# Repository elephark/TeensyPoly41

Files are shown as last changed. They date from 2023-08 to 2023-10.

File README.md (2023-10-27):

# TeensyPoly41

This is loosely based on [TeensyPoly6](https://github.com/albnys/TeensyPoly6)'s schematic, but with many changes of various significance:

* It uses a Teensy 4.1, as the 3.5 wasn't available when this was designed (and is now discontinued).
* It takes the form of a single 2-layer PCB with all pots, switches, and buttons directly affixed. I suppose you could run wires to a front panel if you *really* wanted to.
* It leans much more heavily into the multiplexers, with 8 instead of 1. This results in a more efficient use of pins. 
* It adds a few more controls and enables full ADSR envelopes on the amp and filter.
* It adds LEDs to indicate system state (and greatly aid debugging).
* It adds a rotary dial to select the desired MIDI channel.

### What it looks like
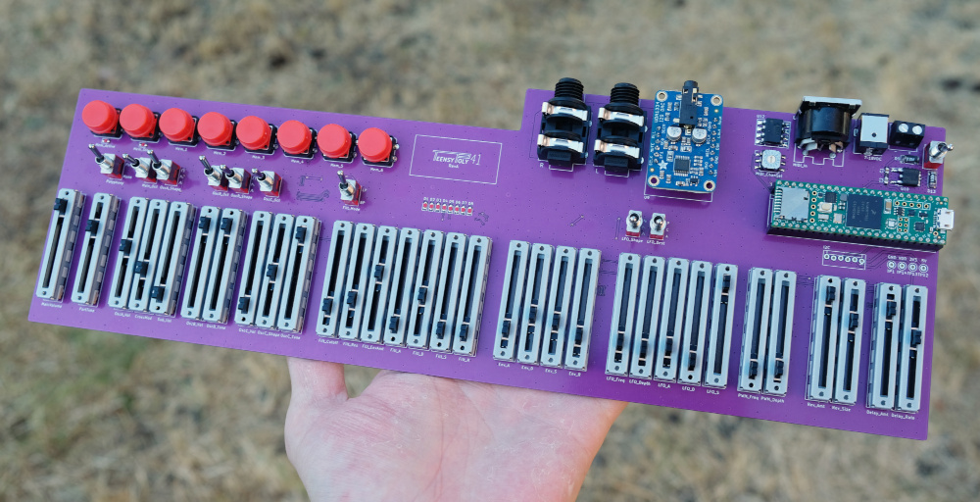
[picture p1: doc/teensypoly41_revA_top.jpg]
TeensyPoly41 top view

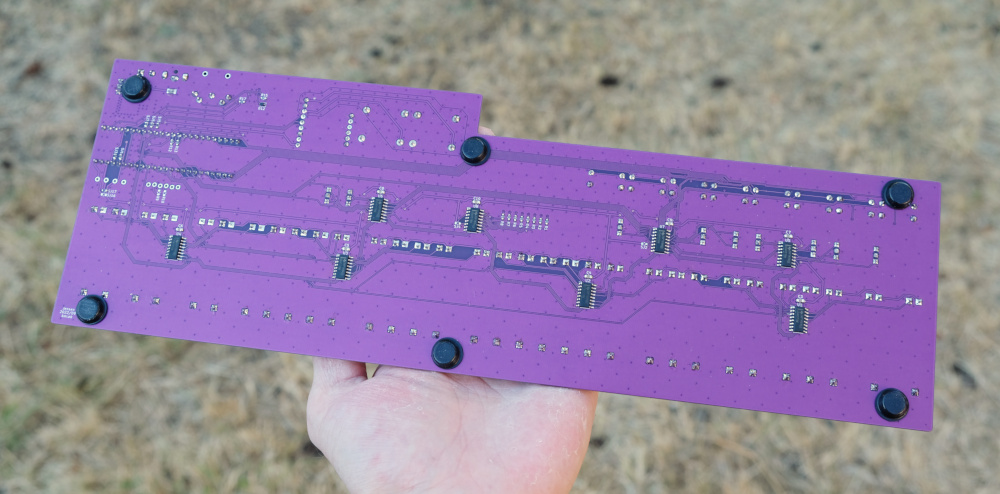
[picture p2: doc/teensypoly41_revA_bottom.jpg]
TeensyPoly41 bottom view


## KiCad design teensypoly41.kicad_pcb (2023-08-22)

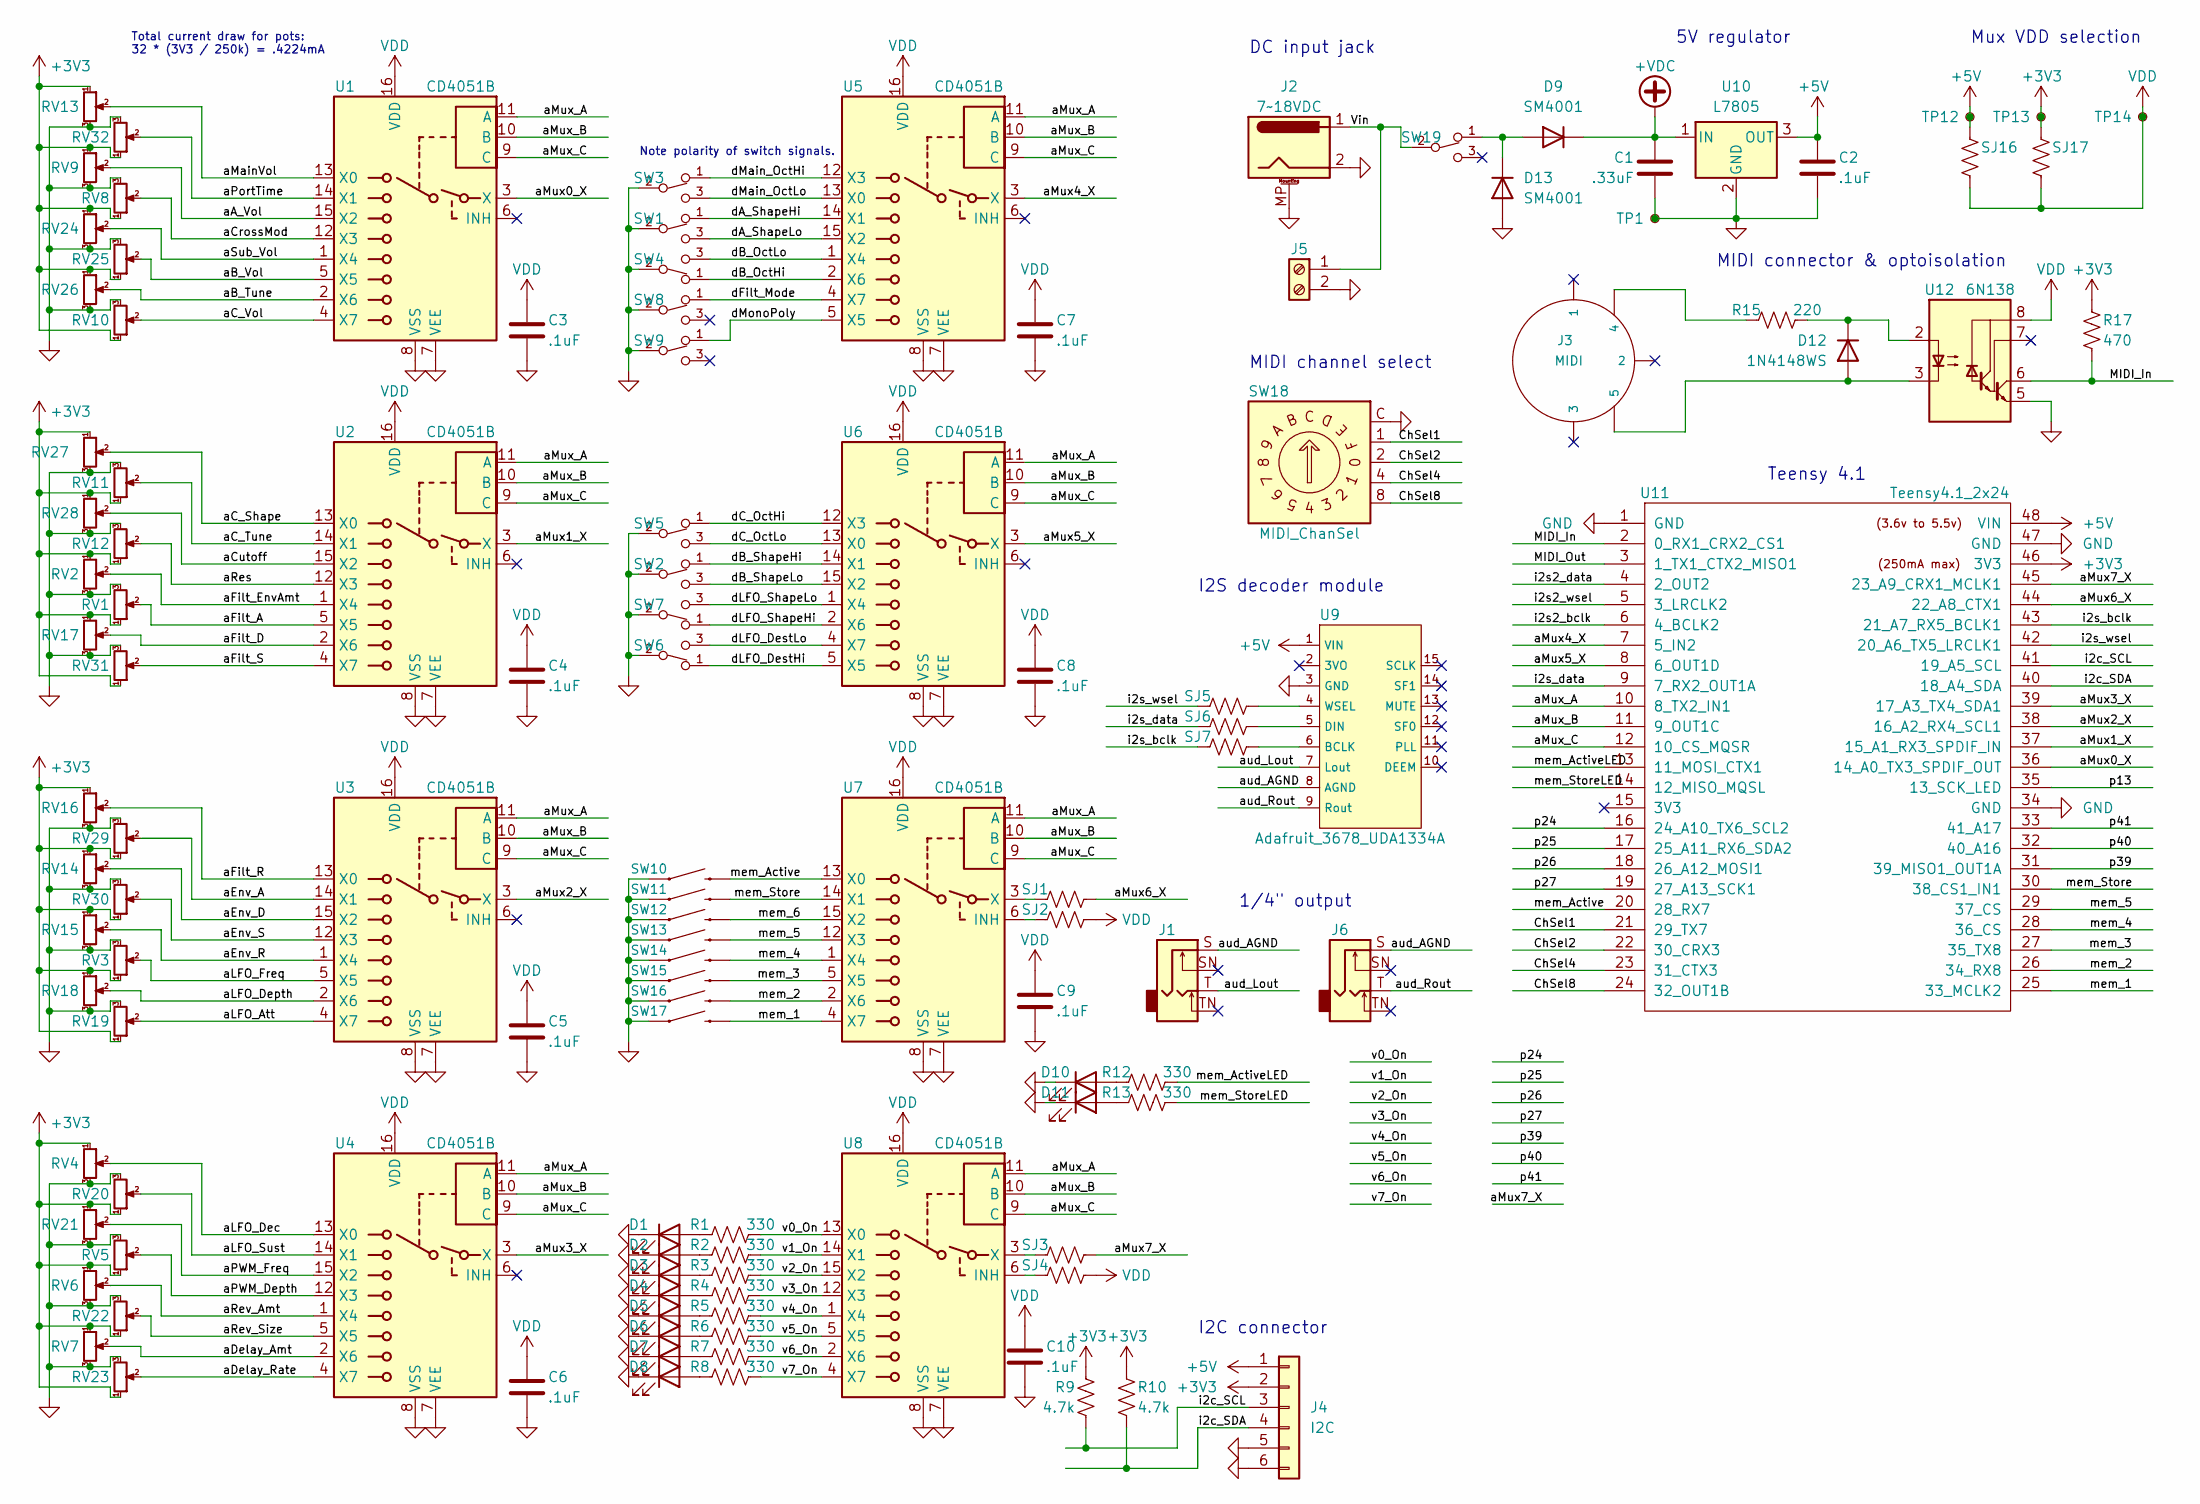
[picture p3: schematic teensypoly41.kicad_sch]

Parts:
C1: .33uF; C_0805_2012Metric_Pad1.18x1.45mm_HandSolder
C2, C3, C4, C5, C6, C7, C8, C9, C10: .1uF; C_0805_2012Metric_Pad1.18x1.45mm_HandSolder
D1: voice0; LED_0805_2012Metric_Pad1.15x1.40mm_HandSolder
D2: voice1; LED_0805_2012Metric_Pad1.15x1.40mm_HandSolder
D3: voice2; LED_0805_2012Metric_Pad1.15x1.40mm_HandSolder
D4: voice3; LED_0805_2012Metric_Pad1.15x1.40mm_HandSolder
D5: voice4; LED_0805_2012Metric_Pad1.15x1.40mm_HandSolder
D6: voice5; LED_0805_2012Metric_Pad1.15x1.40mm_HandSolder
D7: voice6; LED_0805_2012Metric_Pad1.15x1.40mm_HandSolder
D8: voice7; LED_0805_2012Metric_Pad1.15x1.40mm_HandSolder
D9, D13: SM4001; D_MELF
D10: MemActive; LED_0805_2012Metric_Pad1.15x1.40mm_HandSolder
D11: MemStore; LED_0805_2012Metric_Pad1.15x1.40mm_HandSolder
D12: 1N4148WS; D_SOD-323
J1: AudioJack_L; Jack_6.35mm_Neutrik_NMJ4HFD2_Horizontal
J2: 7~18VDC; BarrelJack_CUI_PJ-063AH_Horizontal
J3: MIDI; DIN5-RA-PTH
J4: I2C; MOLEX-1X6_LOCK
J5: Screw_Terminal_01x02; TerminalBlock_Phoenix_MKDS-1,5-2-5.08_1x02_P5.08mm_Horizont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
J6: AudioJack_R; Jack_6.35mm_Neutrik_NMJ4HFD2_Horizontal
R1, R2, R3, R4, R5, R6, R7, R8, R12, R13: 330; R_0603_1608Metric
R9, R10: 4.7k; R_0603_1608Metric
R15: 220; R_0603_1608Metric
R17: 470; R_0603_1608Metric
RV1: Filt_A; Alps_RS301111J00J
RV2: Filt_EnvAmt; Alps_RS301111J00J
RV3: LFO_Freq; Alps_RS301111J00J
RV4: LFO_D; Alps_RS301111J00J
RV5: PWM_Depth; Alps_RS301111J00J
RV6: Rev_Amt; Alps_RS301111J00J
RV7: Delay_Amt; Alps_RS301111J00J
RV8: CrossMod; Alps_RS301111J00J
RV9: OscA_Vol; Alps_RS301111J00J
RV10: OscC_Vol; Alps_RS301111J00J
RV11: OscC_Tune; Alps_RS301111J00J
RV12: Filt_Res; Alps_RS301111J00J
RV13: MainVolume; Alps_RS301111J00J
RV14: Env_D; Alps_RS301111J00J
RV15: Env_R; Alps_RS301111J00J
RV16: Filt_R; Alps_RS301111J00J
RV17: Filt_D; Alps_RS301111J00J
RV18: LFO_Depth; Alps_RS301111J00J
RV19: LFO_A; Alps_RS301111J00J
RV20: LFO_S; Alps_RS301111J00J
RV21: PWM_Freq; Alps_RS301111J00J
RV22: Rev_Size; Alps_RS301111J00J
RV23: Delay_Rate; Alps_RS301111J00J
RV24: Sub_Vol; Alps_RS301111J00J
RV25: OscB_Vol; Alps_RS301111J00J
RV26: OscB_Tune; Alps_RS301111J00J
RV27: OscC_Shape; Alps_RS301111J00J
RV28: Filt_Cutoff; Alps_RS301111J00J
RV29: Env_A; Alps_RS301111J00J
RV30: Env_S; Alps_RS301111J00J
RV31: Filt_S; Alps_RS301111J00J
RV32: PortTime; Alps_RS301111J00J
SJ1, SJ2, SJ3, SJ4, SJ5, SJ6, SJ7, SJ16, SJ17: 0; R_0603_1608Metric
SW1: OscA_Shape; E-Switch_SPDT
SW2: OscB_Shape; E-Switch_SPDT
SW3: Main_Oct; E-Switch_SPDT
SW4: OscB_Oct; E-Switch_SPDT
SW5: OscC_Oct; E-Switch_SPDT
SW6: LFO_Dest; E-Switch_SPDT
SW7: LFO_Shape; E-Switch_SPDT
SW8: Filt_Mode; E-Switch_SPDT
SW9: Mono/Poly; E-Switch_SPDT
SW10: Mem_Active; TACTILE_SWITCH_PTH_12MM
SW11: Mem_Store; TACTILE_SWITCH_PTH_12MM
SW12: Mem_6; TACTILE_SWITCH_PTH_12MM
SW13: Mem_5; TACTILE_SWITCH_PTH_12MM
SW14: Mem_4; TACTILE_SWITCH_PTH_12MM
SW15: Mem_3; TACTILE_SWITCH_PTH_12MM
SW16: Mem_2; TACTILE_SWITCH_PTH_12MM
SW17: Mem_1; TACTILE_SWITCH_PTH_12MM
SW18: MIDI_ChanSel; Nidec_Copal_SH-7010B
SW19: SW_SPDT_ON-ON; E-Switch_SPDT
TP1: GND; TestPoint_Loop_D1.80mm_Drill1.0mm_Beaded
TP12: 5V; TestPoint_Loop_D1.80mm_Drill1.0mm_Beaded
TP13: 3V3; TestPoint_Loop_D1.80mm_Drill1.0mm_Beaded
TP14: VDD; TestPoint_Loop_D1.80mm_Drill1.0mm_Beaded
U1, U2, U3, U4, U5, U6, U7, U8: CD4051B; SOIC-16_3.9x9.9mm_P1.27mm
U9: Adafruit_3678_UDA1334A
U10: L7805; TO-252-2
U11: Teensy4.1_2x24
U12: 6N138; DIP-8_W8.89mm_SMDSocket_LongPads

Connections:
+3V3: J4.2, R9.1, R10.1, R17.1, RV1.1, RV2.1, RV3.1, RV4.1, RV5.1, RV6.1, RV7.1, RV8.1, RV9.1, RV10.1, RV11.1, RV12.1, RV13.1, RV14.1, RV15.1, RV16.1, RV17.1, RV18.1, RV19.1, RV20.1, RV21.1, RV22.1, RV23.1, RV24.1, RV25.1, RV26.1, RV27.1, RV28.1, RV29.1, RV30.1, RV31.1, RV32.1, SJ17.1, TP13.1, U11.46 (3V3)
+5V: C2.1, J4.1, SJ16.1, TP12.1, U9.1 (VIN), U10.3 (OUT), U11.48 (VIN)
+VDC: C1.1, D9.1 (K), U10.1 (IN)
/ChSel1: SW18.1, U11.21 (29_TX7)
/ChSel2: SW18.2, U11.22 (30_CRX3)
/ChSel4: SW18.4, U11.23 (31_CTX3)
/ChSel8: SW18.8, U11.24 (32_OUT1B)
/MIDI_In: R17.2, U11.2 (0_RX1_CRX2_CS1), U12.6 (VO2)
/MIDI_Out: U11.3 (1_TX1_CTX2_MISO1)
/Vin: J2.1, J5.1, SW19.2 (B)
/aA_Vol: RV9.2, U1.15 (X2)
/aB_Tune: RV26.2, U1.2 (X6)
/aB_Vol: RV25.2, U1.5 (X5)
/aC_Shape: RV27.2, U2.13 (X0)
/aC_Tune: RV11.2, U2.14 (X1)
/aC_Vol: RV10.2, U1.4 (X7)
/aCrossMod: RV8.2, U1.12 (X3)
/aCutoff: RV28.2, U2.15 (X2)
/aDelay_Amt: RV7.2, U4.2 (X6)
/aDelay_Rate: RV23.2, U4.4 (X7)
/aEnv_A: RV29.2, U3.14 (X1)
/aEnv_D: RV14.2, U3.15 (X2)
/aEnv_R: RV15.2, U3.1 (X4)
/aEnv_S: RV30.2, U3.12 (X3)
/aFilt_A: RV1.2, U2.5 (X5)
/aFilt_D: RV17.2, U2.2 (X6)
/aFilt_EnvAmt: RV2.2, U2.1 (X4)
/aFilt_R: RV16.2, U3.13 (X0)
/aFilt_S: RV31.2, U2.4 (X7)
/aLFO_Att: RV19.2, U3.4 (X7)
/aLFO_Dec: RV4.2, U4.13 (X0)
/aLFO_Depth: RV18.2, U3.2 (X6)
/aLFO_Freq: RV3.2, U3.5 (X5)
/aLFO_Sust: RV20.2, U4.14 (X1)
/aMainVol: RV13.2, U1.13 (X0)
/aMux0_X: U1.3 (X), U11.36 (14_A0_TX3_SPDIF_OUT)
/aMux1_X: U2.3 (X), U11.37 (15_A1_RX3_SPDIF_IN)
/aMux2_X: U3.3 (X), U11.38 (16_A2_RX4_SCL1)
/aMux3_X: U4.3 (X), U11.39 (17_A3_TX4_SDA1)
/aMux4_X: U5.3 (X), U11.7 (5_IN2)
/aMux5_X: U6.3 (X), U11.8 (6_OUT1D)
/aMux6_X: SJ1.2, U11.44 (22_A8_CTX1)
/aMux7_X: SJ3.2, U11.45 (23_A9_CRX1_MCLK1)
/aMux_A: U1.11 (A), U2.11 (A), U3.11 (A), U4.11 (A), U5.11 (A), U6.11 (A), U7.11 (A), U8.11 (A), U11.10 (8_TX2_IN1)
/aMux_B: U1.10 (B), U2.10 (B), U3.10 (B), U4.10 (B), U5.10 (B), U6.10 (B), U7.10 (B), U8.10 (B), U11.11 (9_OUT1C)
/aMux_C: U1.9 (C), U2.9 (C), U3.9 (C), U4.9 (C), U5.9 (C), U6.9 (C), U7.9 (C), U8.9 (C), U11.12 (10_CS_MQSR)
/aPWM_Depth: RV5.2, U4.12 (X3)
/aPWM_Freq: RV21.2, U4.15 (X2)
/aPortTime: RV32.2, U1.14 (X1)
/aRes: RV12.2, U2.12 (X3)
/aRev_Amt: RV6.2, U4.1 (X4)
/aRev_Size: RV22.2, U4.5 (X5)
/aSub_Vol: RV24.2, U1.1 (X4)
/aud_AGND: J1.S, J6.S, U9.8 (AGND)
/aud_Lout: J1.T, U9.7 (Lout)
/aud_Rout: J6.T, U9.9 (Rout)
/dA_ShapeHi: SW1.1 (A), U5.14 (X1)
/dA_ShapeLo: SW1.3 (C), U5.15 (X2)
/dB_OctHi: SW4.1 (A), U5.2 (X6)
/dB_OctLo: SW4.3 (C), U5.1 (X4)
/dB_ShapeHi: SW2.1 (A), U6.14 (X1)
/dB_ShapeLo: SW2.3 (C), U6.15 (X2)
/dC_OctHi: SW5.1 (A), U6.12 (X3)
/dC_OctLo: SW5.3 (C), U6.13 (X0)
/dFilt_Mode: SW8.1 (A), U5.4 (X7)
/dLFO_DestHi: SW6.1 (A), U6.5 (X5)
/dLFO_DestLo: SW6.3 (C), U6.4 (X7)
/dLFO_ShapeHi: SW7.1 (A), U6.2 (X6)
/dLFO_ShapeLo: SW7.3 (C), U6.1 (X4)
/dMain_OctHi: SW3.1 (A), U5.12 (X3)
/dMain_OctLo: SW3.3 (C), U5.13 (X0)
/dMonoPoly: SW9.1 (A), U5.5 (X5)
/i2c_SCL: J4.3, R9.2, U11.41 (19_A5_SCL)
/i2c_SDA: J4.4, R10.2, U11.40 (18_A4_SDA)
/i2s2_bclk: U11.6 (4_BCLK2)
/i2s2_data: U11.4 (2_OUT2)
/i2s2_wsel: U11.5 (3_LRCLK2)
/i2s_bclk: SJ7.2, U11.43 (21_A7_RX5_BCLK1)
/i2s_data: SJ6.2, U11.9 (7_RX2_OUT1A)
/i2s_wsel: SJ5.2, U11.42 (20_A6_TX5_LRCLK1)
/mem_1: SW17.3 (2), U7.4 (X7), U11.25 (33_MCLK2)
/mem_2: SW16.3 (2), U7.2 (X6), U11.26 (34_RX8)
/mem_3: SW15.3 (2), U7.5 (X5), U11.27 (35_TX8)
/mem_4: SW14.3 (2), U7.1 (X4), U11.28 (36_CS)
/mem_5: SW13.3 (2), U7.12 (X3), U11.29 (37_CS)
/mem_6: SW12.3 (2), U7.15 (X2)
/mem_Active: SW10.3 (2), U7.13 (X0), U11.20 (28_RX7)
/mem_ActiveLED: R12.2, U11.13 (11_MOSI_CTX1)
/mem_Store: SW11.3 (2), U7.14 (X1), U11.30 (38_CS1_IN1)
/mem_StoreLED: R13.2, U11.14 (12_MISO_MQSL)
/p13: U11.35 (13_SCK_LED)
/p24: U11.16 (24_A10_TX6_SCL2)
/p25: U11.17 (25_A11_RX6_SDA2)
/p26: U11.18 (26_A12_MOSI1)
/p27: U11.19 (27_A13_SCK1)
/p39: U11.31 (39_MISO1_OUT1A)
/p40: U11.32 (40_A16)
/p41: U11.33 (41_A17)
/v0_On: R1.2, U8.13 (X0)
/v1_On: R2.2, U8.14 (X1)
/v2_On: R3.2, U8.15 (X2)
/v3_On: R4.2, U8.12 (X3)
/v4_On: R5.2, U8.1 (X4)
/v5_On: R6.2, U8.5 (X5)
/v6_On: R7.2, U8.2 (X6)
/v7_On: R8.2, U8.4 (X7)
GND: C1.2, C2.2, C3.2, C4.2, C5.2, C6.2, C7.2, C8.2, C9.2, C10.2, D1.1 (K), D2.1 (K), D3.1 (K), D4.1 (K), D5.1 (K), D6.1 (K), D7.1 (K), D8.1 (K), D10.1 (K), D11.1 (K), D13.2 (A), J2.2, J2.MP (MountPin), J4.5, J4.6, J5.2, RV1.3, RV2.3, RV3.3, RV4.3, RV5.3, RV6.3, RV7.3, RV8.3, RV9.3, RV10.3, RV11.3, RV12.3, RV13.3, RV14.3, RV15.3, RV16.3, RV17.3, RV18.3, RV19.3, RV20.3, RV21.3, RV22.3, RV23.3, RV24.3, RV25.3, RV26.3, RV27.3, RV28.3, RV29.3, RV30.3, RV31.3, RV32.3, SW1.2 (B), SW2.2 (B), SW3.2 (B), SW4.2 (B), SW5.2 (B), SW6.2 (B), SW7.2 (B), SW8.2 (B), SW9.2 (B), SW10.1, SW11.1, SW12.1, SW13.1, SW14.1, SW15.1, SW16.1, SW17.1, SW18.C, TP1.1, U1.7 (VEE), U1.8 (VSS), U2.7 (VEE), U2.8 (VSS), U3.7 (VEE), U3.8 (VSS), U4.7 (VEE), U4.8 (VSS), U5.7 (VEE), U5.8 (VSS), U6.7 (VEE), U6.8 (VSS), U7.7 (VEE), U7.8 (VSS), U8.7 (VEE), U8.8 (VSS), U9.3 (GND), U10.2 (GND), U11.1 (GND), U11.34 (GND), U11.47 (GND), U12.5 (GND)
unnamed: D1.2 (A), R1.1
unnamed: D2.2 (A), R2.1
unnamed: D3.2 (A), R3.1
unnamed: D4.2 (A), R4.1
unnamed: D5.2 (A), R5.1
unnamed: D6.2 (A), R6.1
unnamed: D7.2 (A), R7.1
unnamed: D8.2 (A), R8.1
unnamed: D10.2 (A), R12.1
unnamed: D11.2 (A), R13.1
unnamed: D12.1 (K), R15.2, U12.2 (C1)
unnamed: D12.2 (A), J3.5, U12.3 (C2)
unnamed: D9.2 (A), D13.1 (K), SW19.1 (A)
unnamed: J3.4, R15.1
unnamed: SJ1.1, U7.3 (X)
unnamed: SJ2.1, U7.6 (INH)
unnamed: SJ3.1, U8.3 (X)
unnamed: SJ4.1, U8.6 (INH)
unnamed: SJ5.1, U9.4 (WSEL)
unnamed: SJ6.1, U9.5 (DIN)
unnamed: SJ7.1, U9.6 (BCLK)
VDD: C3.1, C4.1, C5.1, C6.1, C7.1, C8.1, C9.1, C10.1, SJ2.2, SJ4.2, SJ16.2, SJ17.2, TP14.1, U1.16 (VDD), U2.16 (VDD), U3.16 (VDD), U4.16 (VDD), U5.16 (VDD), U6.16 (VDD), U7.16 (VDD), U8.16 (VDD), U12.8 (VCC)

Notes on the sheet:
Mux VDD selection
Total current draw for pots: 32 * (3V3 / 250k) = .4224mA
I2S decoder module
Teensy 4.1
DC input jack
MIDI channel select
I2C connector
MIDI connector & optoisolation
Note polarity of switch signals.
1/4" output
5V regulator

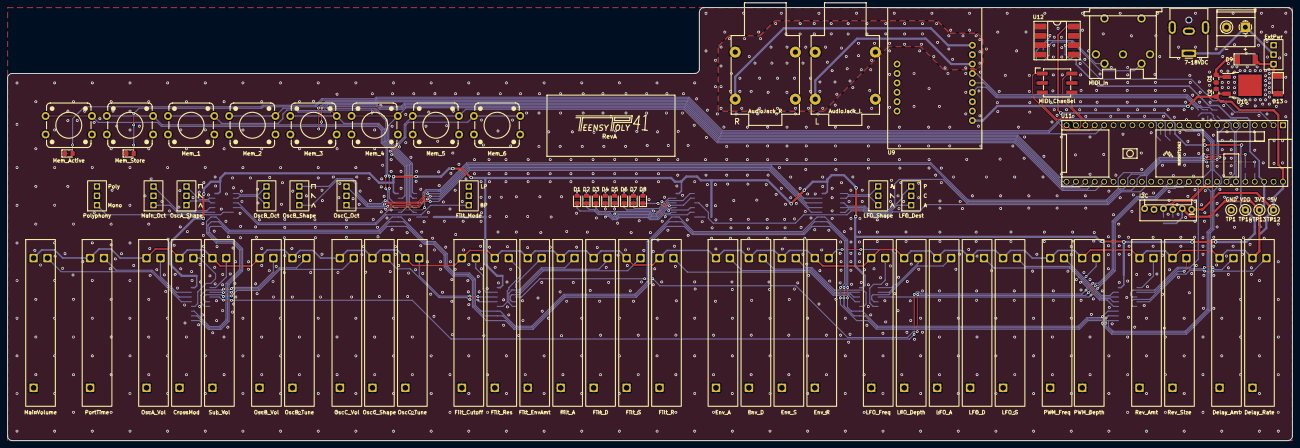
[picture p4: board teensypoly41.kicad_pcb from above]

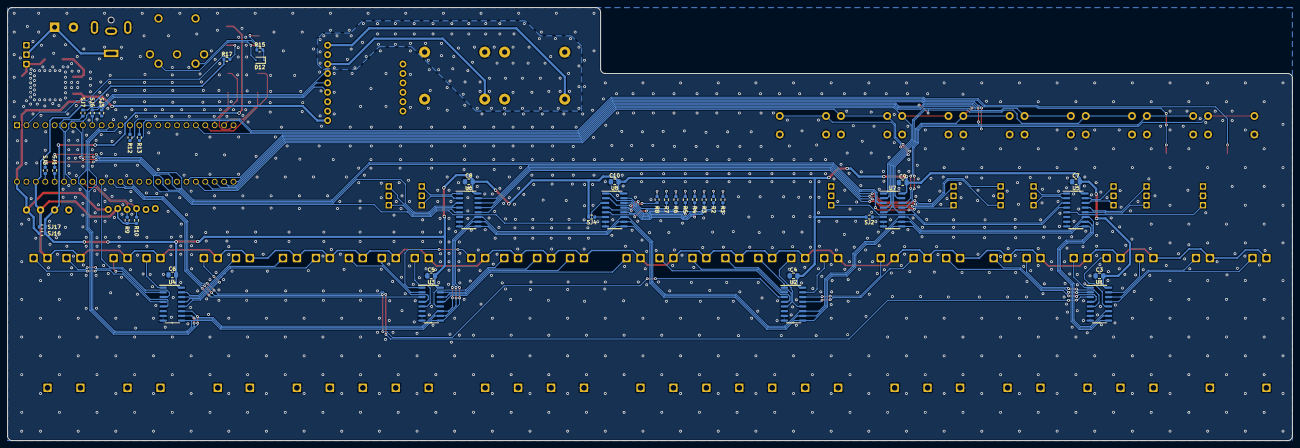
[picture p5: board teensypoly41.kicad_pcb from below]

Board: 2 copper layers, 346.7 x 116.8 mm, 119 parts (40 on the bottom side), 117 nets.

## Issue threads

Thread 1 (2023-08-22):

Fix footprint: DIN-5

elephark, 2023-08-22:

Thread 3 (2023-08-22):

Add footprints of components from modules

elephark, 2023-08-22:
Would allow lower-profile assembly compared to the header + pin heights. Would make it harder to fix if something fails, though.

elephark, 2024-04-16:
Another option to lower the profile while retaining modularity would be to get shorter pins/sockets.

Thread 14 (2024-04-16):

Replace UDA1334A module

elephark, 2024-04-16:
Both [the module](https://www.adafruit.com/product/3678) and [the chip it's based around](https://www.nxp.com/docs/en/data-sheet/UDA1334ATS.pdf) are obsolete. I happen to have two of them (one of which is installed), but anyone else reading this probably doesn't and never will. So if you want to make your very own TeensyPoly41, chances are you're out of luck.

Fortunately, IIRC there's nothing uniquely special about this particular chip as it pertains to this project, it's just an I2S-driven stereo DAC. So that means we have a few options, including:

1. Design a replacement module with a compatible pinout and a different chip. Wouldn't require any changes to TP41 itself, and might even be useful for someone else in the same situation with a different project.
2. Try to find a different (non-obsolete) module that would deliver equivalent functionality, and switch the footprint on the next revision of TP41 to that. Easy changes at worst.
3. The above, but just make an adapter board. The lazy approach.
4. Redo the audio interface entirely, knocking out issue [#3](https://github.com/elephark/TeensyPoly41/issues/3) in the process and/or retaining a modular format but with a different pinout/socket.
